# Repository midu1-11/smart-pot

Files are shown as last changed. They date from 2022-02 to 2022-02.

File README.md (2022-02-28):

# 智能花盆  
## 一.项目简介
本项目是利用寒假时间做的一个练手项目，目的是学习vscode+platformio ESP32开发，嵌入式GUI框架LVGL的移植和使用。platformio IDE具有编译速度快、结构清晰等特点。
## 二.开源链接
演示视频:  https://www.bilibili.com/video/BV1ZU4y1Z7sd?spm_id_from=333.999.0.0
  
hardware文件夹中有原理图的pdf和pcb的gerber文件以及外壳stl文件  
  
software文件夹的lib文件夹为空，需要自行导入对应版本的库文件  
  
库文件:  
· ArduinoJson  6.19.1  
· lvgl8  
· TFT_eSPI
## 三.开发环境
1.vscode+platformio ESP32开发  
  
2.vs2019 lvgl模拟器 GUI界面设计与仿真  
  
3.solidworks 2021 外壳设计  
  
4.立创eda pcb设计  
  
## 四.功能展示
图1 主板正面  
主板正面  
图2 主板背面  
主板背面  
图3 无线充电座内部  
无线充电座内部  
图4 整体外观正面  
整体外观正面  
图5 整体外观背面  
整体外观背面  
图6 主页面  
主页面  
图7  光照强度页面
光照强度页面  
图8 土壤湿度页面  
土壤湿度页面  
图9 亮度调节页面  
亮度调节页面  
## 五.技术详情  
1.天气温度等api由心知天气提供  
  
2.时间api由网上大佬提供  
  
3.光照强度由光敏电阻测得  
  
4.土壤湿度是我取出土壤湿度模块前端的金属片得到的  
  
5.屏幕亮度通过P波配合mos管调节tft屏幕背光端电压实现  
  
6.无线充电采用优信5V1A模块实现  
  
7.本页面的图片来自于路过图床  
  
## 六.项目的不足  
无线充电解决方案由于外壳的阻隔距离，充电效果只能耗电速度持平。只有使用背部typec才能充上电。  
  
获取时间的api有时不稳定，存在获取失败的情况  
  
代码中移植了文件系统，pcb也预留了SD卡槽，但为了实现流畅的动画效果，所有的图片都是以C文件的形式存储进内部RAM(520kB)中。  
  
由于时间问题项目没有实现蓝牙和扫码配网功能，各种页面也有待开发  
  
本项目部分参考了FranHawk和稚晖君的资料，十分感谢！

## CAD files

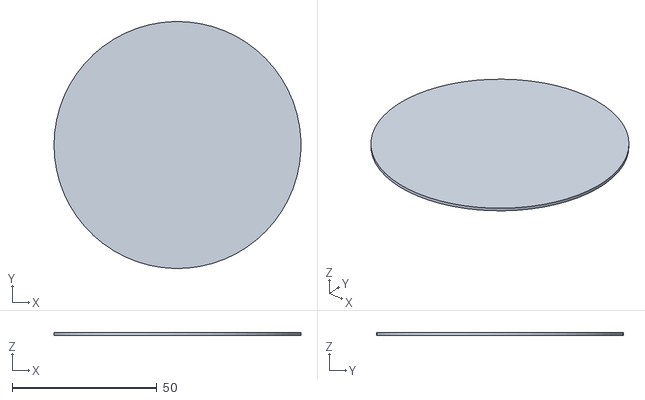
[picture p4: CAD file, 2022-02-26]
1.hardware/外壳/wireless-charger-bottom.STL
85.2 x 85.2 x 1.00

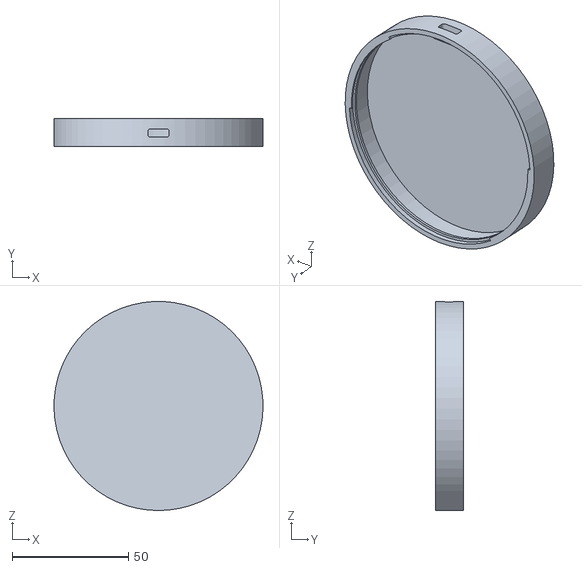
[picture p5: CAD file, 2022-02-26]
1.hardware/外壳/wireless-charger-shell.STL
90.0 x 12.0 x 90.0

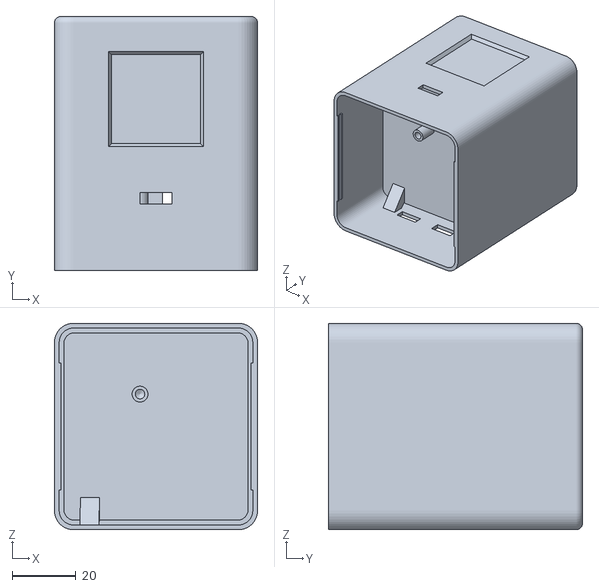
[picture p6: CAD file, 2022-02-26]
1.hardware/外壳/smart-pot-shell.STL
64.0 x 80.0 x 65.0

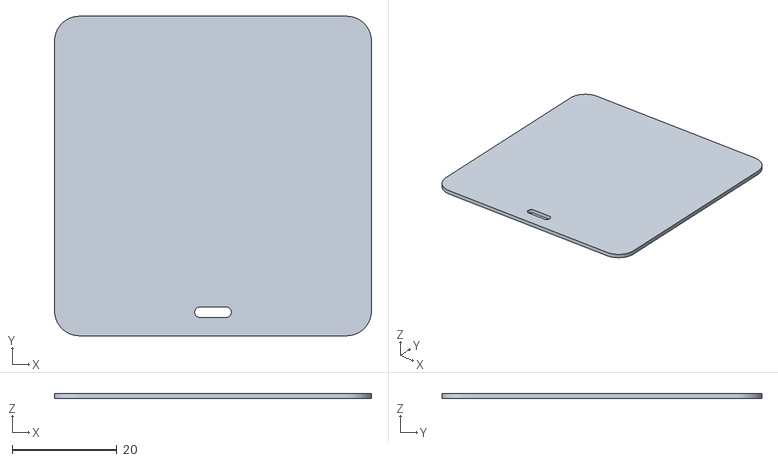
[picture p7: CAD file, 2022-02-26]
1.hardware/外壳/smart-pot-bottom.STL
60.5 x 61.0 x 1.00

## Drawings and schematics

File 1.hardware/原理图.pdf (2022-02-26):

# 电源管理

# USB转串口

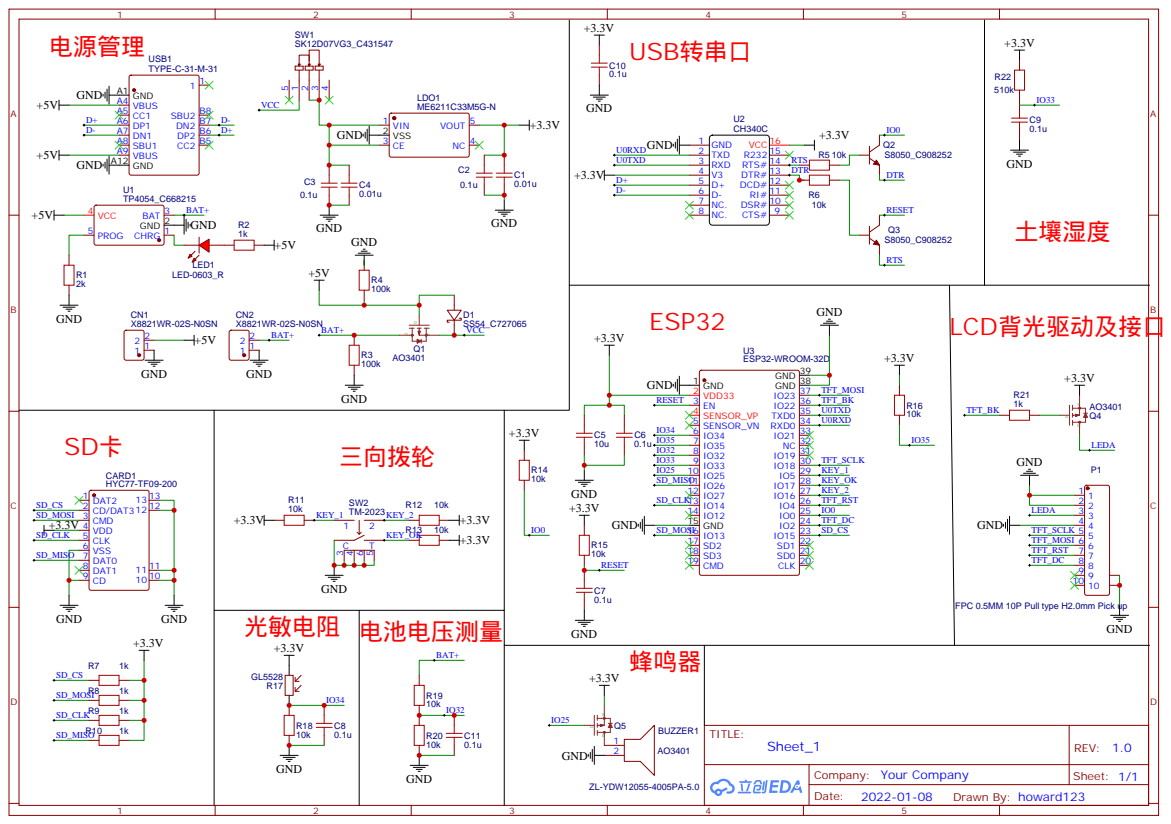
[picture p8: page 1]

FPC 0.5MM 10P Pull type H2.0mm Pick up

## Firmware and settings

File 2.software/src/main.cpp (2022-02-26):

#include <lvgl.h>
#include <Arduino.h>
#include "functions.h"

void setup()
{
   buzzer_init();

   Serial.begin(115200);

   sd_init();

   lvgl_init();

   mysystem_init();

   page_init();

   wifi_init();

   Serial.println("Setup done");
}

void loop()
{

   lv_timer_handler(); /* 在循环中让lvgl处理一些相应的事件 lvgl核心函数*/

   monitor();

   delay(5);
}

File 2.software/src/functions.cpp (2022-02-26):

#include <lvgl.h>
#include <TFT_eSPI.h>
#include <lv_demo.h>
#include "lv_port_fatfs.h"
#include "sd_card.h"
#include <Arduino.h>
#include <FS.h>
#include <SPI.h>
#include <SD.h>
#include "light_intensity.h"
#include "home.h"
#include "humi_soil.h"
#include "luminance.h"
#include <WiFi.h>
#include <ArduinoJson.h>
#include <iostream>
#include <string>

/*时间api*/
#define NTP1 "ntp1.aliyun.com"
#define NTP2 "ntp2.aliyun.com"
#define NTP3 "ntp3.aliyun.com"
/*wifi*/
const char *ssid = "dyp";          // WIFI账户
const char *password = "00000000"; // WIFI密码

/*心知天气api*/
const char *host = "api.seniverse.com";
const char *privateKey = "SvbWq65M_Nn6d0gBt";
const char *city = "beijing";
const char *language = "en";

/*天气信息结构体*/
struct WetherData
{
    char city[32];
    char weather[64];
    char high[32];
    char low[32];
    char humi[32];
    char date[32];
    char fengsu[32];
};

extern lv_obj_t *two;
extern lv_obj_t *three;
extern lv_obj_t *four;
extern lv_obj_t *five;

extern lv_style_t font_style;
extern lv_obj_t *label3;
extern lv_obj_t *label4;
extern lv_obj_t *label5;
extern lv_obj_t *bar1;
extern lv_obj_t *bar2;
extern lv_obj_t *slider1;

char s[100];
//当前页面号
int state = 0;
//当前页面是否在调节亮度界面
int condition = 0;
char str1[10];
//亮度  0-100
float screen_luminance = 70;

TFT_eSPI tft = TFT_eSPI();

/*屏幕的宽高在这里修改*/
static const uint32_t screenWidth = 240;
static const uint32_t screenHeight = 240;

static lv_disp_draw_buf_t draw_buf;
static lv_color_t buf[screenWidth * 10];

//开启日志后调用的函数，启用该功能需要修改lvgl_conf.h的对应功能
#if LV_USE_LOG != 0
/* Serial debugging */
void my_print(lv_log_level_t level, const char *file, uint32_t line, const char *fn_name, const char *dsc)
{
    Serial.printf("%s(%s)@%d->%s\r\n", file, fn_name, line, dsc);
    Serial.flush();
}
#endif

/*页面切换动画 左*/
void page_change1(lv_obj_t *from_page, lv_obj_t *to_page)
{
    lv_anim_t a;
    lv_anim_init(&a);                                          //初始化动画对象
    lv_anim_set_var(&a, from_page);                            //为对象设置一个动画
    lv_anim_set_values(&a, 0, -lv_obj_get_width(two));         //设置一个动画的开始和结束值
    lv_anim_set_time(&a, 1000);                                //设置一个动画时间
    lv_anim_set_exec_cb(&a, (lv_anim_exec_xcb_t)lv_obj_set_x); //设置一个动画回调
    lv_anim_set_path_cb(&a, lv_anim_path_linear);              //设置一个动画的路径
    lv_anim_start(&a);                                         //开始动画

    lv_anim_t b;
    lv_anim_init(&b);                                          //初始化动画对象
    lv_anim_set_var(&b, to_page);                              //为对象设置一个动画
    lv_anim_set_values(&b, lv_obj_get_width(two), 0);          //设置一个动画的开始和结束值
    lv_anim_set_time(&b, 1000);                                //设置一个动画时间
    lv_anim_set_exec_cb(&b, (lv_anim_exec_xcb_t)lv_obj_set_x); //设置一个动画回调
    lv_anim_set_path_cb(&b, lv_anim_path_linear);              //设置一个动画的路径
    lv_anim_start(&b);                                         //开始动画
}

/*页面切换动画 右*/
void page_change2(lv_obj_t *from_page, lv_obj_t *to_page)
{
    lv_anim_t a;
    lv_anim_init(&a);                                          //初始化动画对象
    lv_anim_set_var(&a, from_page);                            //为对象设置一个动画
    lv_anim_set_values(&a, 0, lv_obj_get_width(two));          //设置一个动画的开始和结束值
    lv_anim_set_time(&a, 1000);                                //设置一个动画时间
    lv_anim_set_exec_cb(&a, (lv_anim_exec_xcb_t)lv_obj_set_x); //设置一个动画回调
    lv_anim_set_path_cb(&a, lv_anim_path_linear);              //设置一个动画的路径
    lv_anim_start(&a);                                         //开始动画

    lv_anim_t b;
    lv_anim_init(&b);                                          //初始化动画对象
    lv_anim_set_var(&b, to_page);                              //为对象设置一个动画
    lv_anim_set_values(&b, -lv_obj_get_width(two), 0);         //设置一个动画的开始和结束值
    lv_anim_set_time(&b, 1000);                                //设置一个动画时间
    lv_anim_set_exec_cb(&b, (lv_anim_exec_xcb_t)lv_obj_set_x); //设置一个动画回调
    lv_anim_set_path_cb(&b, lv_anim_path_linear);              //设置一个动画的路径
    lv_anim_start(&b);                                         //开始动画
}

/* 刷新屏幕 */
void my_disp_flush(lv_disp_drv_t *disp, const lv_area_t *area, lv_color_t *color_p)
{
    uint32_t w = (area->x2 - area->x1 + 1);
    uint32_t h = (area->y2 - area->y1 + 1);

    tft.startWrite();
    tft.setAddrWindow(area->x1, area->y1, w, h);
    tft.pushColors((uint16_t *)&color_p->full, w * h, true);
    tft.endWrite();

    lv_disp_flush_ready(disp);
}

/* 蜂鸣器初始化 */
void buzzer_init()
{
    pinMode(25, OUTPUT);
    digitalWrite(25, 1);
}

/* lvgl初始化 */
void lvgl_init()
{
    lv_init();
    tft.begin();        /* TFT init */
    tft.setRotation(0); /* 旋转屏幕，n * 90度 ，3表示270度*/

    lv_disp_draw_buf_init(&draw_buf, buf, NULL, screenWidth * 10); /*建立一个屏幕宽*10大小的缓冲区*/

    /*初始化屏幕*/
    static lv_disp_drv_t disp_drv;
    lv_disp_drv_init(&disp_drv);
    /*设置参数*/
    disp_drv.hor_res = screenWidth;
    disp_drv.ver_res = screenHeight;
    disp_drv.flush_cb = my_disp_flush;
    disp_drv.draw_buf = &draw_buf;
    lv_disp_drv_register(&disp_drv);

    /*初始化输入设备*/
    static lv_indev_drv_t indev_drv;
    lv_indev_drv_init(&indev_drv);
    indev_drv.type = LV_INDEV_TYPE_POINTER;
    lv_indev_drv_register(&indev_drv);

    /*初始化文件系统*/
    lv_fs_if_init();
}

/* sd卡初始化 */
void sd_init()
{
    SPIClass *sd_spi = new SPIClass(HSPI);
    if (!SD.begin(15, *sd_spi)) // SD-Card SS pin is 15
    {
        Serial.println("Card Mount Failed");
    }
}

/* 系统初始化 */
void mysystem_init()
{
    pinMode(5, INPUT);  // KEY1
    pinMode(17, INPUT); // KEY_OK
    pinMode(16, INPUT); // KEY2

    /*背光引脚输出pwm*/
    ledcSetup(0, 10000000, 8);
    ledcAttachPin(22, 0);
    ledcWrite(0, screen_luminance);
}

/* 页面初始化 lvgl按照创建的顺序默认覆盖 所以注意初始化顺序*/
void page_init()
{
    page5_init();
    page4_init();
    page2_init();
    page3_init();
}

int wind_spend_set(char *x)
{
    if (x[1] == '.')
        return x[0] - 48;
    else if (x[2] = '.')
        return (x[0] - 48) * 10 + x[1] - 48;
}

/* 设置时间 */
void setClock()
{
    struct tm timeinfo;
    if (!getLocalTime(&timeinfo))
    { //如果获取失败，就开启联网模式，获取时间
        Serial.println("Failed to obtain time");
        WiFi.disconnect(false);
        WiFi.mode(WIFI_STA); //开启网络
        WiFi.begin(ssid, password);
        while (WiFi.status() != WL_CONNECTED)
        {
            delay(500);
            Serial.print(".");
        }
        configTime(8 * 3600, 0, NTP1, NTP2, NTP3);
        return;
    }
    Serial.println(&timeinfo, "%F %T %A"); // 格式化输出:2021-10-24 23:00:44 Sunday
    Serial.print(asctime(&timeinfo));      //默认打印格式：Mon Oct 25 11:13:29 2021
    WiFi.disconnect(true);
}
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
